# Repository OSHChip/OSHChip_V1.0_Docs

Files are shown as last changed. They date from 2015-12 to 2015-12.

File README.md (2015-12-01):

# OSHChip_V1.0 Design Files

These are the design files for **OSHChip** version 1.0

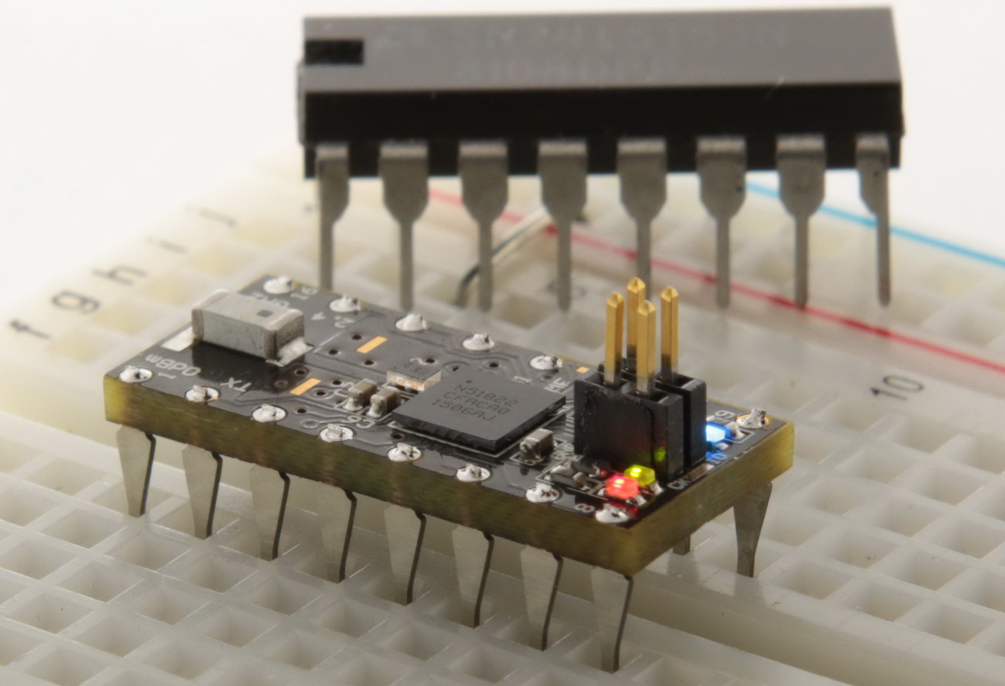
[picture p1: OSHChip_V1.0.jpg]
OSHChip_V1.0
<p></p>

The PCB design files are in the directory *Design_Files* and were
created with Altium Designer Release 10

Since you may not have access to Altium Designer, I have also
included all the Gerber files and the Excelon drill file in the
directory *Gerbers_and_Drill_Files*.

In the *Other_Files* directory, you will find the following:
* OSHChip_V1.0___Schematic.PDF
* OSHChip_V1.0___PCB_Prints.PDF
* OSHChip_V1.0___Assembly_Drawings.PDF
* OSHChip_V1.0___Bill_of_Materials.xls
* OSHChip_V1.0___Bill_of_Materials.PDF

<div align="center">
<a rel="license" href="http://creativecommons.org/licenses/by-sa/4.0/">

</a><br />
<span xmlns:dct="http://purl.org/dc/terms/" property="dct:title">
OSHChip</span> by <a xmlns:cc="http://creativecommons.org/ns#" href="www.oshchip.com" 
property="cc:attributionName" rel="cc:attributionURL">Philip Freidin</a>
 is licensed under a <br><a rel="license" href="http://creativecommons.org/licenses/by-sa/4.0/">
 Creative Commons Attribution-ShareAlike 4.0 International License</a>.
</div>

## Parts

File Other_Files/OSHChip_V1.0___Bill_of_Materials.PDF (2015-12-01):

# | Description | Designator | Footprint | Comment | Quantity | Supplier | Supplier Part Number

1 | Chip Antenna 2.4 GHz | A1 | AMCA31-2R450G-S1F-T | Chip Antenna, 2.450 GHz | 1 | Mouser | 815-CA312R450GS1FT
2 | Capacitor 12 pF 0402 50V NP0 5% | C1, C2 | 0402 CAP RouteThru | 12 pF 0402 | 2 | Digi-Key | 1276-1178-1-ND
3 | Capacitor 0.1 uF 0402 10 V X5R 10% | C3, C5, C8, C90402 CAP RouteThru | | 0.1 uF 0402 | 4 | Digi-Key | 1276-1001-1-ND
4 | Capacitor 1.0 nF 0402 25 V X7R 10% | C4 | 0402 CAP RouteThru | 1.0 nF 0402 | 1 | Newark | 06R4614
5 | Capacitor 47 nF 0402 16V X7R 10% | C6 | 0402 CAP RouteThru | 47 nF 0402 | 1 | Digi-Key | 587-1225-1-ND
6 | Capacitor 2.2 nF 0402 50 V X7R 10% | C7 | 0402 CAP RouteThru | 2.2 nF 0402 | 1 | Digi-Key | 311-1037-1-ND
7 | LED Red 630 nm 0402 | D1 | 0402 LED Route Thru RED | Red LED 0402 | 1 | Mouser | 604-APHHS1005SURCK
8 | LED APHHS1005CGCK Green 570nm 0402 | D2 | 0402 LED Route Thru GREEN | Green LED 0402 | 1 | Mouser | 604-APHHS1005CGCK
9 | LED Blue 466 nm 0402 | D3 | 0402 LED Route Thru BLUE | Blue LED 0402 | 1 | Mouser | 720-LBQH9G-N1P2-35-1
10 | DIP Pin 8 Etched | J1, J2 | SIP 8 P2.54MM | DIP Pin 8 | 2 | Fliptronics | OSHChip_Pin_8
11 | FTSH-102-01-L-D | J3 | HDR_2x2_1.27mm-Through_Hole_SWDFTSH-102-01-L-D | | 1 | Newark | 01R3028
12 | CPW 125mil , over ground plane, .062" board, 50 Ohm | L1 | CPW_125 | CPW 125mil | 1 | Fliptronics | CPW-125mil
13 | Balun matched to WLCSP nRF61822 | L2 | BAL-ST-WLCSP | Balun WLCSP | 1 | Mouser | 511-BAL-NRF02D3
14 | Resistor 4.7K 0402 1/16 W 1% | R1, R2, R3 | 0402 Res Route Thru | 4.7K 0402 | 3 | Mouser | 603-AC0402FR-074K7L
15 | Multi-protocol Bluetooth Low Energy and 2.4GHz proprietary system-on-chip | U1 | BGA62C40P9X9_383X383X55 | nRF51822_CFAC WLCSP | 1 | Digi-Key | 1490-1041-1-ND
16 | 16MHz Xtal, 2.5mmx2.0mm, 10ppm, 8 pF | X1 | BT-XTAL_2520 | 16 MHz 2.5mm x 2.0mm | 1 | Digi-Key | SER3913CT-ND
Bill of Materials for OSHChip V1.0 | 11/30/2015

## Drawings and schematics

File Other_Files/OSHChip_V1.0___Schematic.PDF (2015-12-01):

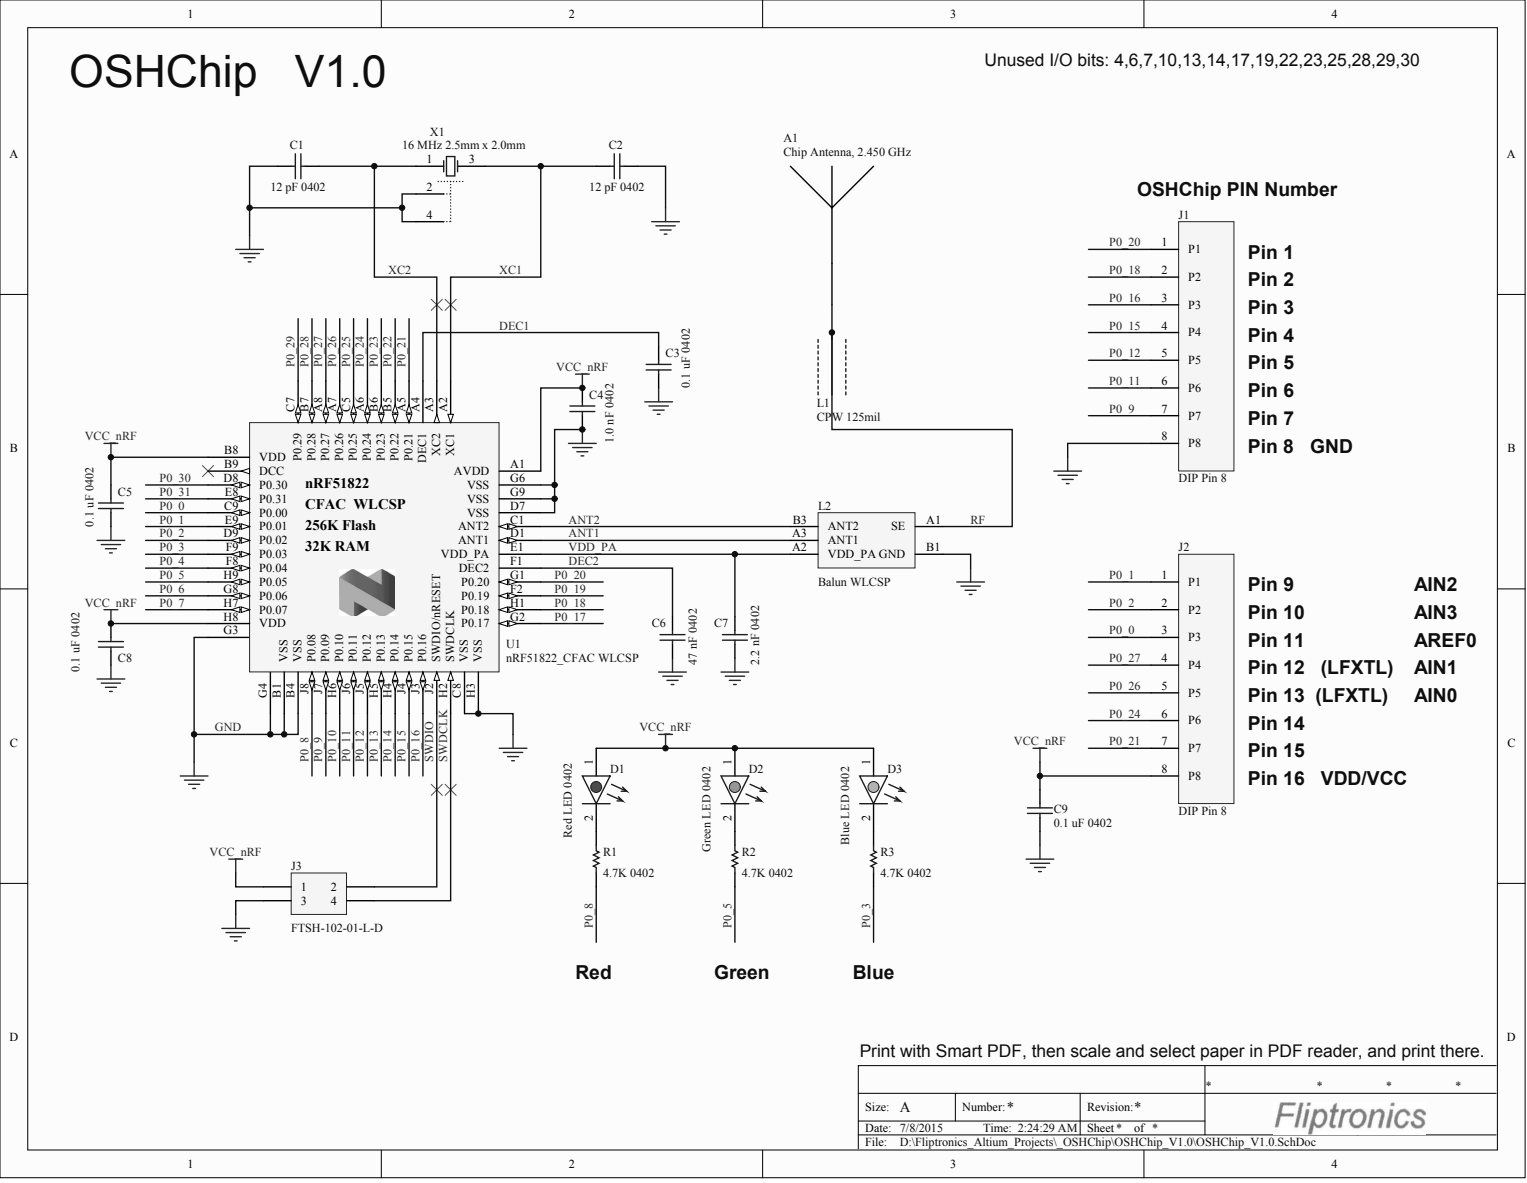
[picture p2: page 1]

Print with Smart PDF, then scale and select paper in PDF reader, and print there.

Size: A | Number: * | Revision: *

7/8/2015 Time: 2:24:29 AM | | Sheet * of *

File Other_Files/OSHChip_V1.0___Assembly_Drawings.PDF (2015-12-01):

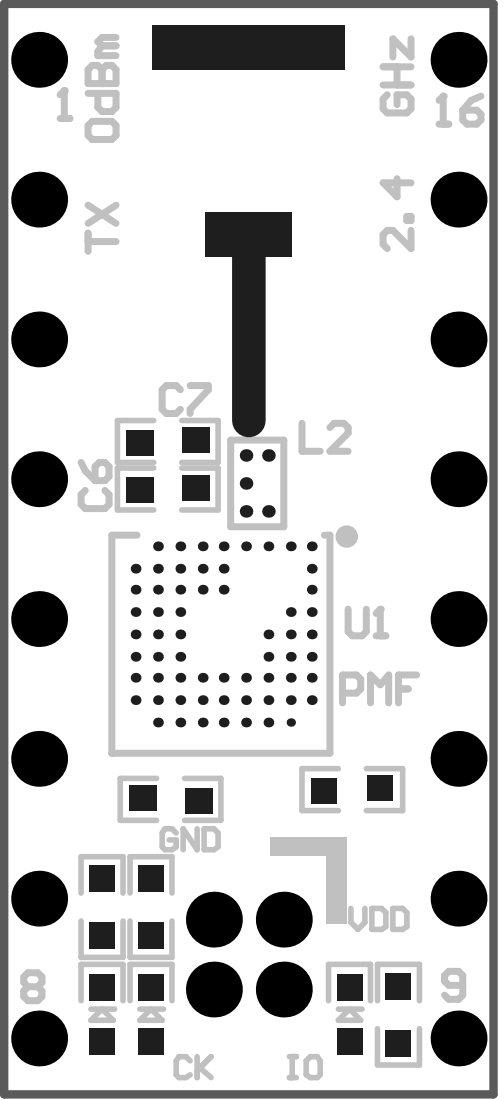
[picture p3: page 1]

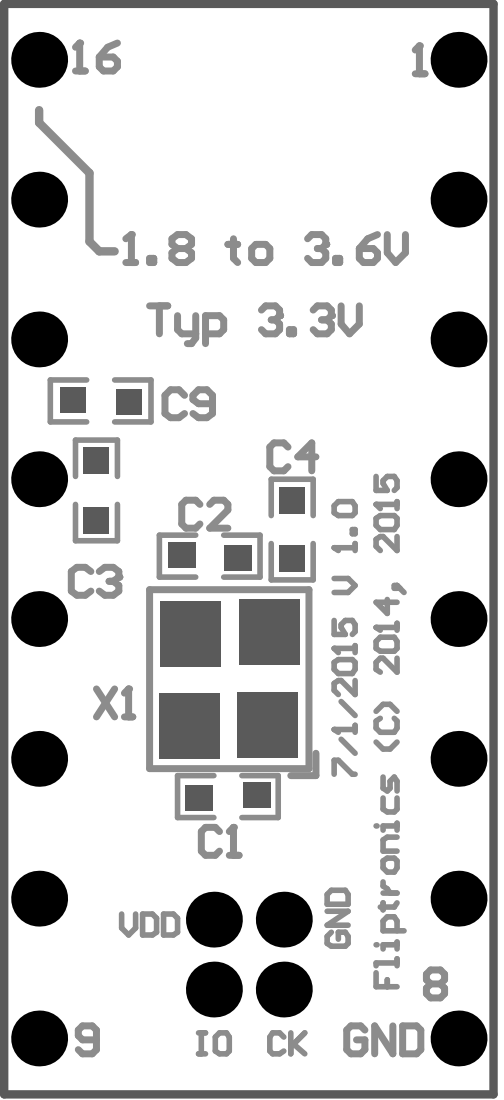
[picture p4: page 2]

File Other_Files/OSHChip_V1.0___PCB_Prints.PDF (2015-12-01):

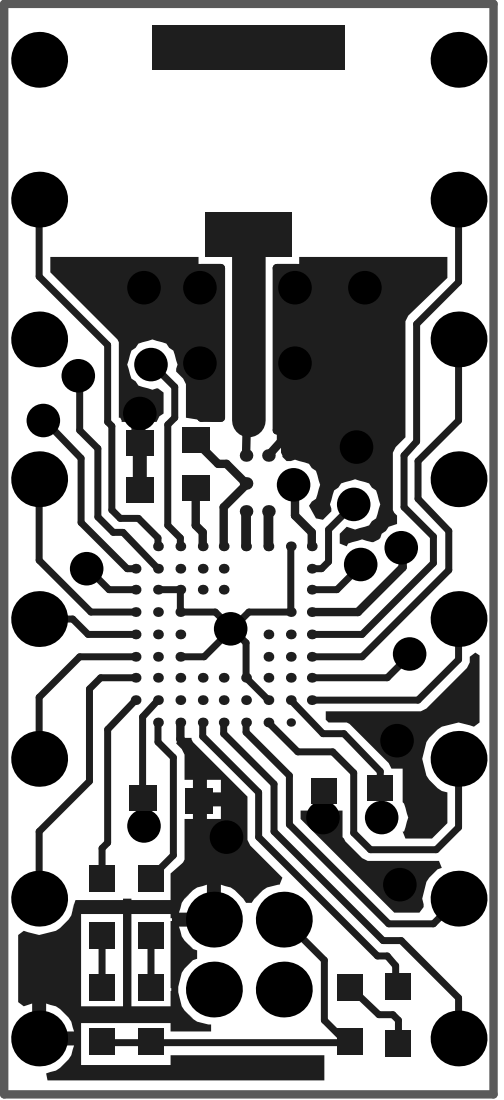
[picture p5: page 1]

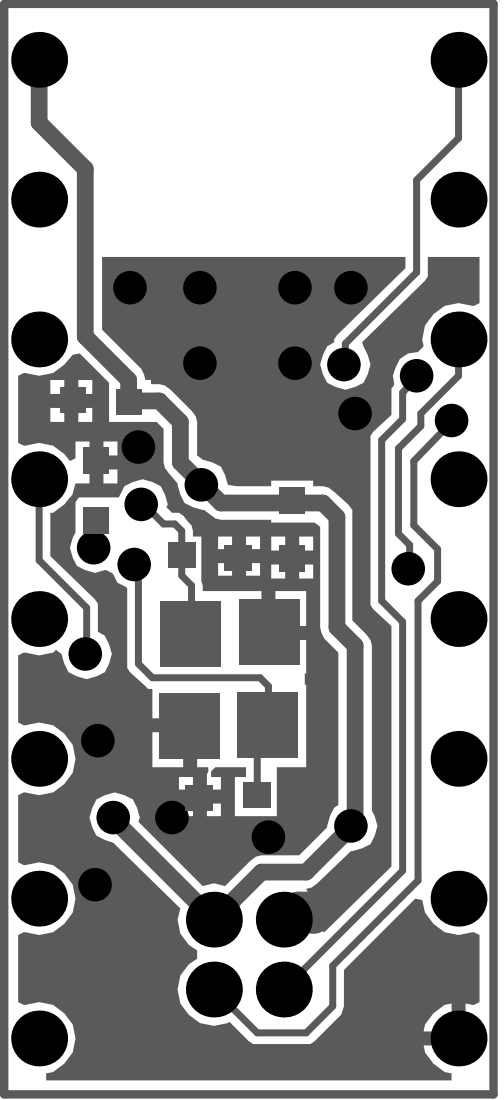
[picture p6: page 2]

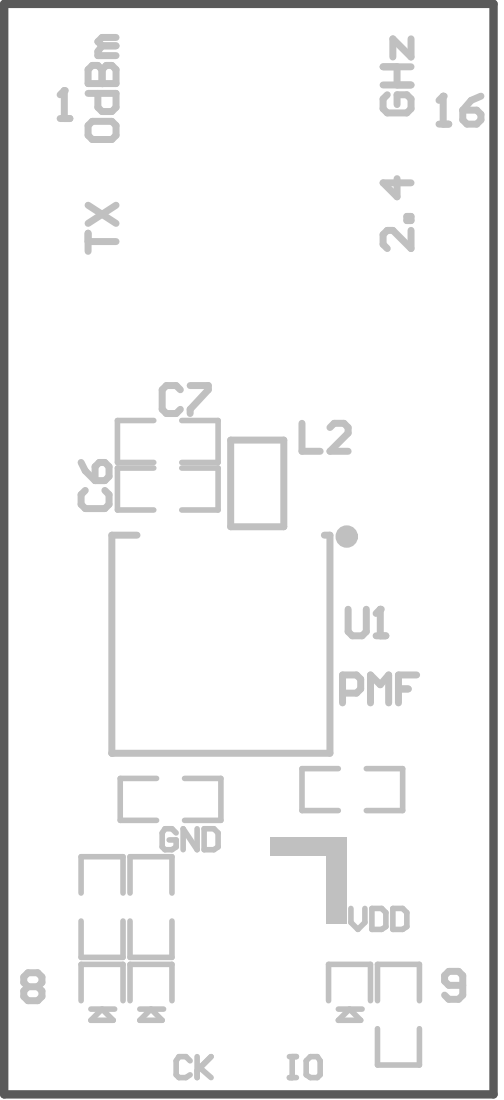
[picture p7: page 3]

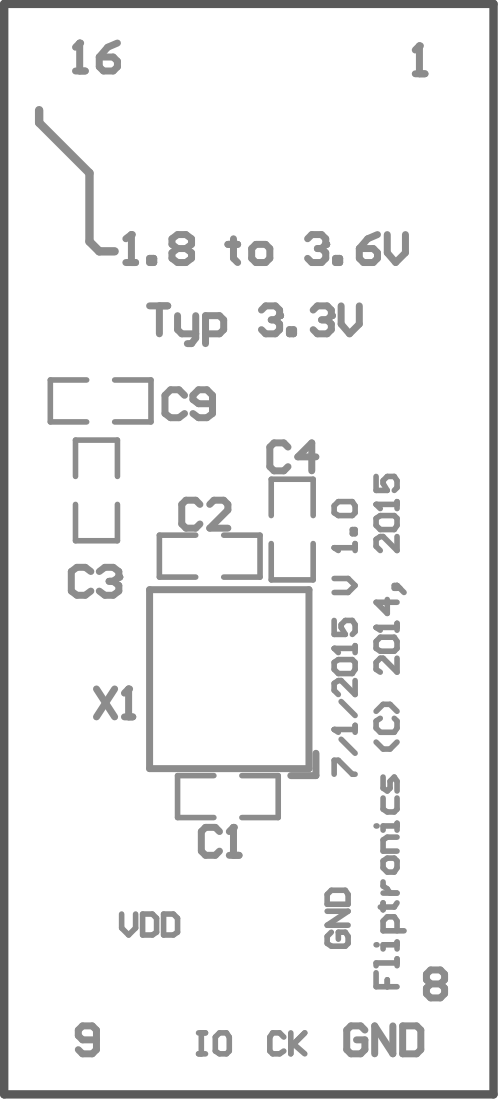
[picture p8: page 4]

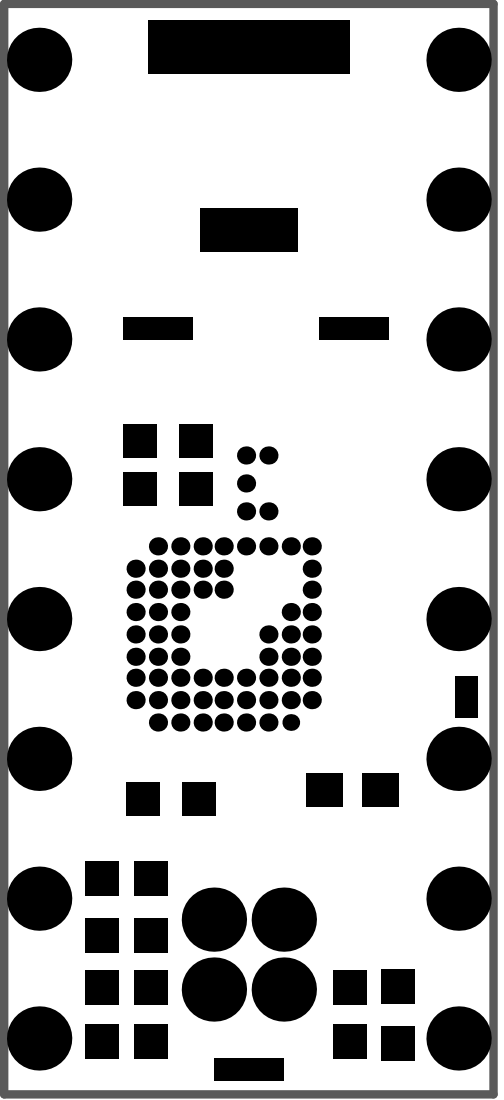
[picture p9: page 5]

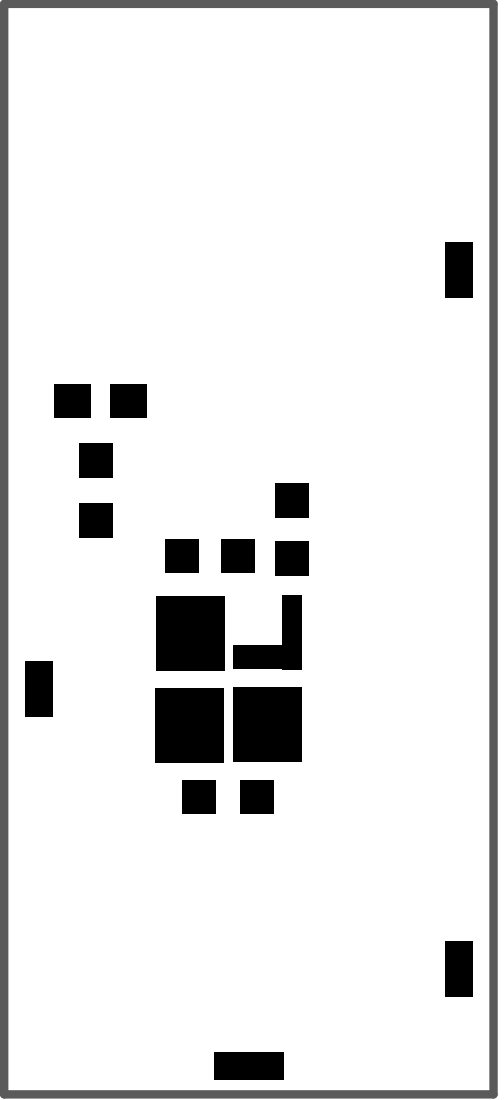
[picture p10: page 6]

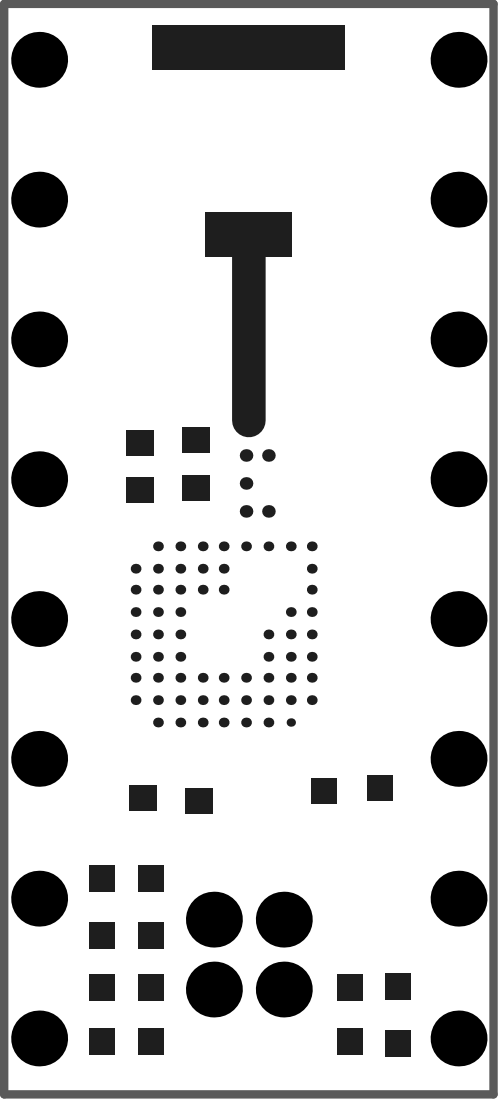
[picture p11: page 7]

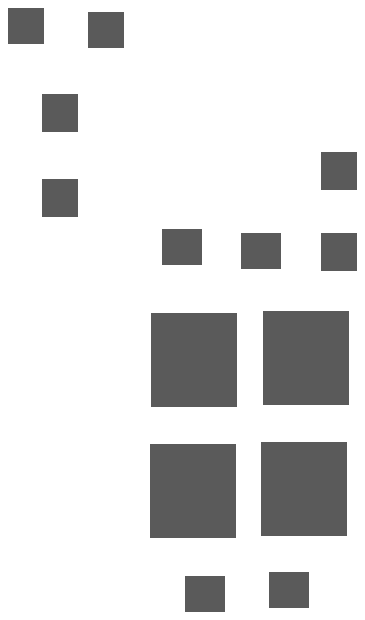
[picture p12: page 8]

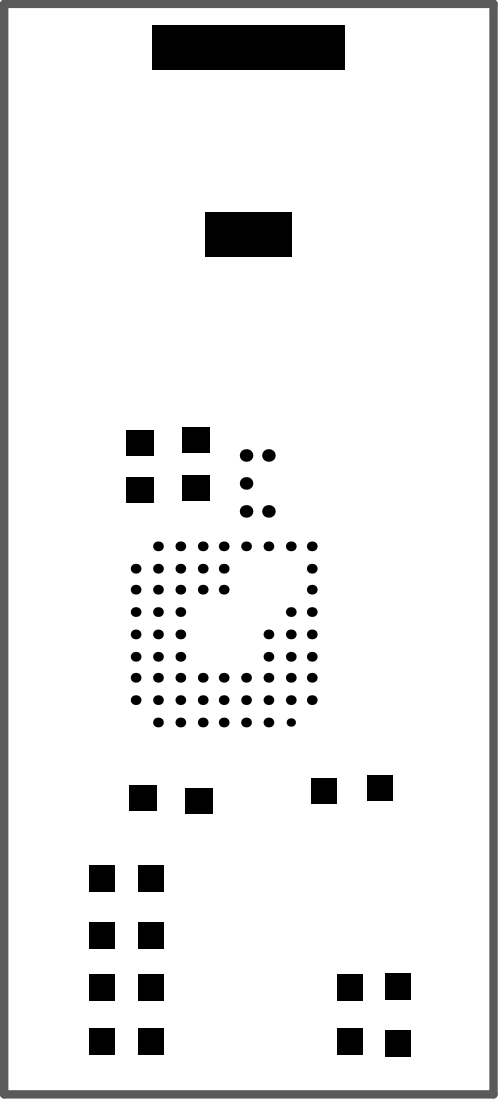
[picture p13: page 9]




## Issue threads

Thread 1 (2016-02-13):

"DIP Pin 8 Etched" part not found

Ragooman, 2016-02-13:
Hello,
This is not really an issue but more of a question.
I really like the use of the DIP style pin legs in your project. I've seen others before but they were not very compatible with both the breadboard and IC Sockets. As there were to thick and caused the contacts to spread out too much and eventually loosen the contacts. I think the type you have is a btter solution.
But I couldn't find the part mentioned in your BOM, "DIP Pin 8 Etched" at the listed supplier. I looked up Fliptronics but they don't seem to offer this on their website.
Is this a custom part or did they stop selling this ?
thanks,
Dan

OSHChip, 2016-02-14:
Hi Dan,

The pins are custom designed and manufactured for OSHChip by Fliptronics (which is my consulting company). The square (some times gold plated) pins that everyone else seems to use are 0.025" square, and are difficult to push into the breadboards, and they damage the breadboard as you have observed. The OSHChip pins are made of [Nickel Silver](https://en.wikipedia.org/wiki/Nickel_silver) and are 0.010" thick. This material was selected for its shiny silver color and surface, ease of soldering, and material strength, and limited tolerance to being bent. The tail of the pin that goes into the breadboard are the same dimensions as standard DIP pins: 0.020" wide and 0.010" thick. This is what the breadboards were designed for, so OSHChips are relatively easy to insert and remove from a breadboard, and don't damage it any more than normal IC pins.

Quite a few people have expressed an interest in my custom pins, so I am going to be making them a product, but I have other OSHChip related challenges that are ahead of that.

Currently they are made as an 8 pin strip, with a supporting bar at the non-soldered end. After the other ends are soldered into the PCB, the  support bar is easily broken off by flexing it a few times. The joint from the pins to the support bar is deliberately weakened.

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

Ragooman, 2016-02-16:
This is great news. This reminds me of the IC socket pins I used long ago in the 70s for the kits we built. This was way cheaper than the plastic IC sockets. It was made the same way, each socket pin is individually fabricated, on a strip, came on a roll. Much like the molex connector socket pins except they were 100mil for DIPs. And so you just cutoff how much you needed for a 14pin, 16pin, etc. I look forward to when you add this to your online store. thanks !

adrianfreed, 2016-07-26:
Hi, I was curious what the time line was for this interesting strip of pins you are planning to make available.

OSHChip-Owner, 2016-07-26:
Hi Adrian,
About 3 months ago I had a Eureka moment and came up with a totally different way to make these pins, and much more importantly, a far superior way to hold them in alignment for soldering into a PCB. I then made the scary decision to pay for the tooling costs (NRE) and rather high minimum order quantities (MOQ) and the result is that about a week ago I received a bucket load of pin strips in lengths of 8, 14, and 20.  My current plan is to make them available via Tindie and maybe other distributors, around the end of August, or early September.  I am planning to price them per pin, but have not settled on final pricing.  If you have the time, and would be willing to discuss what you feel acceptable pricing should be, please call me on (408) 737-0295 afternoon or evening.  I would also be interested in how you would use them.

Thanks for your interest,
Philip

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

adrianfreed, 2016-08-03:
thanks for the update.
I am looking at packaging some basic analog and cmos chips into  a dip format . One design has 16 pins, the other 24pins. I am struggling a bit because some of the chips I want to use aren't available in packages smaller than TSSOP which is a tight squeeze between those pin rows. QFN's are much easier to fit! My target retail price is $20-$25: so my price/pin hopes will be much in line with what you have been doing.

OSHChip-Owner, 2017-01-05:
These Pins are now described on the main web site [Flip-Pins](http://oshchip.org/products/Flip-Pins_Product.html) and can be purchased on Tindie, or at Evil Mad Scientist Labs (EMSL) or at Sparkfun.

Closed 2017-01-05.

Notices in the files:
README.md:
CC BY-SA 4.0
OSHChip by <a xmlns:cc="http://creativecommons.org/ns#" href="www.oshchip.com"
